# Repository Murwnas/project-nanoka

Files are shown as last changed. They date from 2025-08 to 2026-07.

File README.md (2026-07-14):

# project-nanoka
KiCad 3D render

Project Nanoka is a Raspberry Pi Pico based audio output/input PCB. It exposes two audio terminals (input and output) as well as seven general-purposes input/output lines for external control. 

The PCB can be powered either through the Raspberry Pi's USB port, or through the power terminal. This requires a power module (also hosted on GitHub).

Right now, this is a prototype, and it's usefulness likely applies only to me. There are better solutions out there. I mainly created this to learn KiCad, and more broadly, PCB design which was always an interest of mine. This PCB should not be reproduced for your own personal use. If you do use it, **all responsibility is yours**. 

Known issues from previous version:
1. No audio output because the buffer chip is wired incorrectly (Input to A1, output to Y2)
2. Audio relay footprint is wrong
3. Audio relay footprint was accidentally flipped to the back of the board
4. C3 and C5 footprints are wrong
5. Audio input/output terminals are labelled in reverse
6. A potentiometer to adjust audio levels exists, but adjusting it below 220 ohms can cause damage to the Raspberry Pi

Fixed issues:
1. Audio is now properly routed from the buffer's A2 to Y2
2. Both relay issues have been fixed
3. Audio input/output terminals are labelled correctly and more clearly
4. C3 and C5 footprints fixed
5. Replaced potentiometer with a 220 ohm resistor

Improvements:
1. Replaced transistors with cheaper, more readily available ones
2. Tweaked transistor base resistor to draw less power from GPIO
4. Switched from a 4-layer setup to a 2-layer setup, making this cheaper to produce
5. Moved terminals closer to each other
6. General layout improvements
7. Symbols, footprints and 3D models are now packed in the repository

Ideas for the future:
1. Use a muxer IC to mix audio.
2. Switch from PWM audio to I2C audio for a cleaner signal.
3. Maybe re-design with SMD components to make this signafinantly smaller and elegant (but the THT components make it easier to assemble).

This was produced last summer. It worked (and still does to this day). The only issue it has is audio popping during start and stop of playback.

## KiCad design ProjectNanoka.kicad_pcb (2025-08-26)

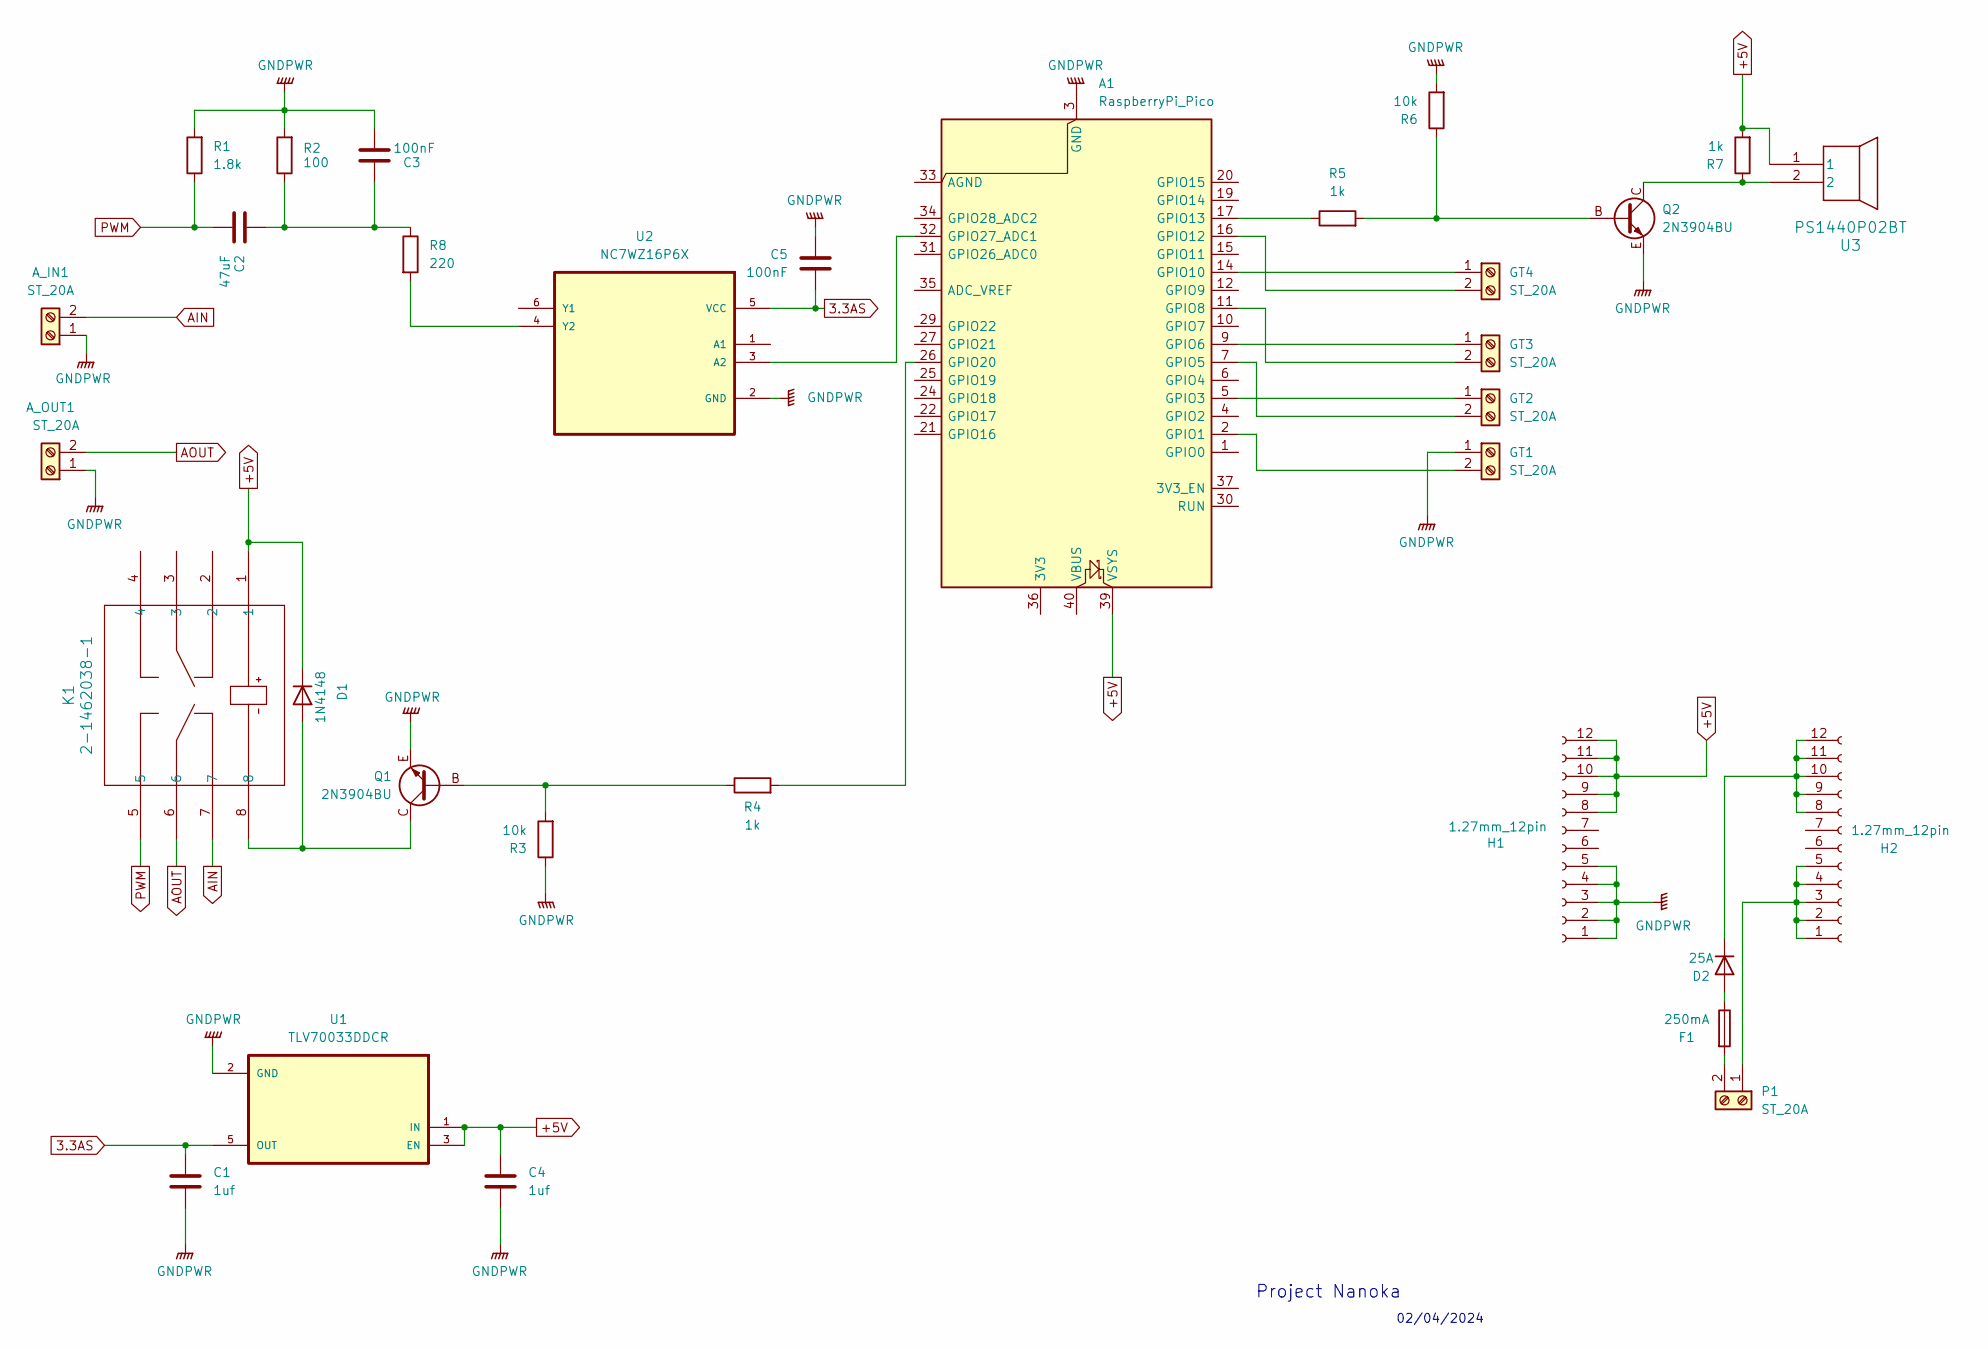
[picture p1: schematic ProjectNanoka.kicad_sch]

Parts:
A1: RaspberryPi_Pico; RPi_Pico_SMD_TH
A_IN1: ST_20A; CONN_1935161_PXC
A_OUT1: ST_20A; CONN_1935161_PXC
C1, C4: 1uf; CAP_C330C_MR_X7R_KEM
C2: 47uF; CAP_UUQ_5X5P4_NCH
C3, C5: 100nF; CAP_C320_KEM
D1: 1N4148; D_DO-35_SOD27_P7.62mm_Horizontal
D2: 25A; P33_D5.4x7.5
F1: 250mA; 20x300_FUSE_HOLDER_0PTF0078P_LTF
GT1, GT2, GT3, GT4: ST_20A; CONN_1935161_PXC
H1, H2: 1.27mm_12pin; PinHeader_1x12_P1.27mm_Vertical_Modded
K1: 2-1462038-1; RELAY8-TH_NON-LATCH_1-COIL
P1: ST_20A; CONN_1935161_PXC
Q1, Q2: 2N3904BU
R1: 1.8k; STA_CF14_STP
R2: 100; STA_CF14_STP
R3, R6: 10k; STA_RNF14_STP
R4, R5, R7: 1k; STA_RNF14_STP
R8: 220; STA_RNMF14_STP
U1: TLV70033DDCR; SOT95P280X110-5N
U2: NC7WZ16P6X; SOT65P210X110-6N; MPN NC7WZ16P6X
U3: PS1440P02BT; PS1440P02BT_TDK

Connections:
3.3AS: C1.1, C5.1, U1.5 (OUT), U2.5 (VCC)
+5V: A1.39 (VSYS), C4.1, D1.1 (K), H1.8, H1.9, H1.10, H1.11, H1.12, K1.1, R7.2, U1.1 (IN), U1.3 (EN), U3.1
AIN: A_IN1.2, K1.7
AOUT: A_OUT1.2, K1.6
GNDPWR: A1.3 (GND), A1.8 (GND), A1.13 (GND), A1.18 (GND), A1.23 (GND), A1.28 (GND), A1.38 (GND), A_IN1.1, A_OUT1.1, C1.2, C3.2, C4.2, C5.2, GT1.1, H1.1, H1.2, H1.3, H1.4, H1.5, Q1.E, Q2.E, R1.2, R2.2, R3.1, R6.2, U1.2 (GND), U2.2 (GND)
unnamed: A1.2 (GPIO1), GT1.2
unnamed: A1.5 (GPIO3), GT2.1
unnamed: A1.7 (GPIO5), GT2.2
unnamed: A1.9 (GPIO6), GT3.1
unnamed: A1.11 (GPIO8), GT3.2
unnamed: A1.14 (GPIO10), GT4.1
unnamed: A1.16 (GPIO12), GT4.2
unnamed: A1.17 (GPIO13), R5.1
unnamed: A1.26 (GPIO20), R4.2
unnamed: A1.32 (GPIO27_ADC1), U2.3 (A2)
unnamed: C2.1, C3.1, R2.1, R8.1
unnamed: D1.2 (A), K1.8, Q1.C
unnamed: D2.2 (A), F1.1
unnamed: D2.1 (K), H2.8, H2.9, H2.10, H2.11, H2.12
unnamed: H2.1, H2.2, H2.3, H2.4, H2.5, P1.1
unnamed: F1.2, P1.2
unnamed: Q1.B, R3.2, R4.1
unnamed: Q2.B, R5.2, R6.1
unnamed: Q2.C, R7.1, U3.2
unnamed: R8.2, U2.4 (Y2)
PWM: C2.2, K1.5, R1.1

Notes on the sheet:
Project Nanoka
02/04/2024

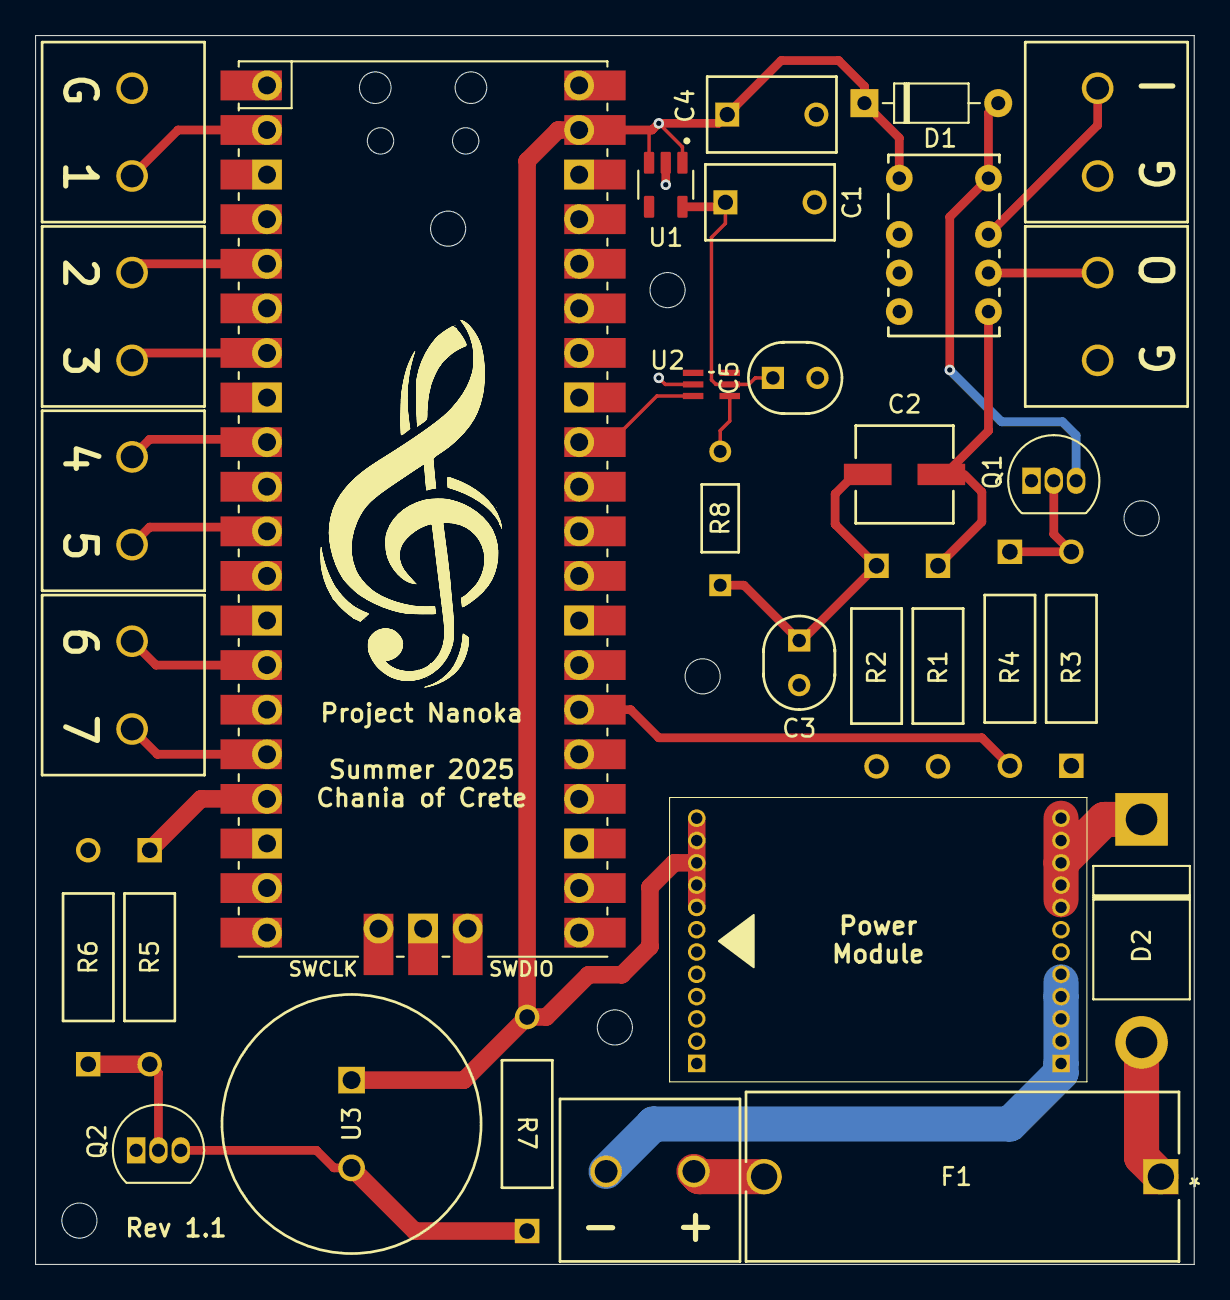
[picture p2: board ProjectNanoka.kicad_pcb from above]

Board: 2 copper layers, 66.0 x 70.0 mm, 32 parts (0 on the bottom side), 26 nets.
